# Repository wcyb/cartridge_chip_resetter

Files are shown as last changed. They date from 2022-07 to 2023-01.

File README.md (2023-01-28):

# Cartridge chip resetter

This repository contains electronic schematics and source code for resetters of chips placed on ink and toner cartridges. Resetters allow the same cartridge to be reused any number of times after it has been refilled with ink or toner respectively. This allows for maximum reduction in printing costs, as you only need to refill the cartridges and reset their chips when necessary, instead of buying a new cartridge every time.

Ready-made resetters of Chinese origin, for different cartridge models can be purchased on various sites, such as AliExpress or eBay. If you want to make such a resetter for your printer yourself, you can use this repository.

For more information on how the DRM protections used in printer cartridges work, and how to analyze them and create resetters yourself, see my research paper, available here: [research paper](https://czasopisma.uwm.edu.pl/index.php/ts/article/view/7634).

Currently, this repository contains documentation of resetters for printers and MFPs from two manufacturers - EPSON and RICOH.

These resetters should work with chips from cartridges used in the following printer/MFP models:

| EPSON | RICOH |
|---|---|
| B40W | SG 2100N |
| BX300F | SG 3100 SNw |
| BX310F | SG 3110DN |
| BX600FW | SG 3110DNw |
| BX610FW | SG 3110 SFNw  |
| D78 | SG 3120B SFNw |
| D92 | SG 7100DN |
| D120 | SP 100 |
| DX4000 | SP 100E |
| DX4050 | SP 100SU |
| DX4400 | SP 100SF |
| DX4450 | SP 112 |
| DX5000 | SP 112SU |
| DX5050 | SP 112SF |
| DX6000 | |
| DX6050 | |
| DX7000 | |
| DX7000F | |
| DX7400 | |
| DX7450 | |
| DX8400 | |
| DX8450 | |
| DX9000 | |
| DX9400 | |
| DX9400F | |
| DX9450 | |
| DX945 | |
| S20 | |
| S21 | |
| SX100 | |
| SX105 | |
| SX110 | |
| SX115 | |
| SX200 | |
| SX210 | |
| SX215 | |
| SX218 | |
| SX400 | |
| SX405 | |
| SX405WiFi | |
| SX410 | |
| SX415 | |
| SX510W | |
| SX515W | |
| SX600FW | |
| SX610FW | |

Cartridge models:

| EPSON | Compatible resetter | RICOH | Compatible resetter |
|---|---|---|---|
| T0711 | DX4050 | GC 41K  | SG2100N |
| T0712 | DX4050 | GC 41C  | SG2100N |
| T0713 | DX4050 | GC 41M  | SG2100N |
| T0714 | DX4050 | GC 41Y  | SG2100N |
| | | GC 41KL | SG2100N |
| | | GC 41CL | SG2100N |
| | | GC 41ML | SG2100N |
| | | GC 41YL | SG2100N |
| | | _IC 41_ | SG2100N |
| | | 407166  | SP112 |

This gives a total of 13 cartridge models and 1 waste ink container model, used in 60 different printer and MFP models.

A data map for the chip used in each cartridge model is also included in the folders for each of the resetters. It is not guaranteed to be completely compatible with chip data from printer models other than the one on which it was based. However, if there are any differences, they should be minor and not affect the functioning of the resetter.

I don't plan to create any more resetters as I don't own any other printer models. If someday I have a new printer, then maybe the documentation for another resetter will appear here.

### Non-commercial use only.

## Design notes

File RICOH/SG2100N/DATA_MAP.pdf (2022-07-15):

## Data map of RICOH AFICIO SG 2100N cartridge chip’s memory

| 0x00 | 0x01 | 0x02 | 0x03 | 0x04 | 0x05 | 0x06 | 0x07
0x00 | M¹ | CV² | B 3 | Region⁴ | T 5 | IC⁶ | 0x0 | 0xFF
0x08 | IIA⁷ | 0x0 | 0xFF | | | | ISR⁸ | 0xFF
0x10 | Cartridge serial number⁹
0x18 | 0xFF
0x20 | EDP code¹⁰
0x28 | PL¹¹ | 0x0
0x30 | 0xFF
0x38
0x40 | IED¹² | Ink amount | Printer work status (PWS)
0x48 | PWS | IIC¹³ | HRC¹⁴ | HCC¹⁵ | AIC¹⁶ | ISF¹⁷ | SF¹⁸ | 0xFF
0x50 | 0xFF | | | | | | CPC¹⁹
0x58 | BPC²⁰ | | EPC²¹ | | TPC²²
0x60 | Amount of ink used
0x68 | 0xFF
0x70 | Cartridge status
0x78 | Printer serial number

1 Model
2 Cartridge version
3 Brand
4 Region of destination of the cartridge (e.g. Europe) 5 Type
6 Ink color – 1:black, 2:cyan, 3:magenta, 4:yellow 7 The initial amount of ink in percent
8 The number of refills of the ink delivery system
9 Two digits are coded on each byte
10 One of the following: 405761, 405762, 405763, 405764, 405765, 405766, 405767, 405768 11 Percentage of ink left (100 means full, 255 means not initialized)
12 Ink expiration date
13 The amount of ink used during cartridge initialization
14 The number of print head refresh cycles
15 The number of print head cleaning cycles
16 The number of air intrusions into the ink delivery system 17 The number of fills of the ink delivery system
18 Status flag
19 The number of color pages printed
20 The number of black and white pages printed 21 The number of economy color pages printed 22 The number of total pages printed

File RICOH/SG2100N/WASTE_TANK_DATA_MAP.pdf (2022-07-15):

Data map of RICOH AFICIO SG 2100N waste tank chip’s memory

| 0x00 | 0x01 | 0x02 | 0x03 | 0x04 | 0x05 | 0x06 | 0x07
0x00 | M¹ | CV² | B 3 | CN⁴ | 0x0 | Amount of ink used (AIU)
0x08 | AIU | Serial number (SN)
0x10 | SN | TF⁵ | | TCF⁶ | 0x0
0x18 | Printer serial number
0x20 | 0x0
0x28 | TPC⁷
0x30 | 0x0 | WSF⁸ | 0x0
0x38 | CPC⁹
0x40
0x48 | 0x0
0x50
0x58 | Tank status | 0x0 | SF¹⁰ | WSF
0x60 | WSF | 0x0 | WSF | 0x0
0x68 | 0x0 | AIS¹¹ | CPC
0x70 | 0x0 | BPC¹² | Counter (C)
0x78 | C | 0x0
0x80 | AIS | 0x0 | ISF¹³
0x88 | 0x0
⁞ | ⁞
0xFF | 0x0

1 Model
2 Cartridge version
3 Brand
4 Control number
5 Threshold value indicating a full tank
6 Threshold value indicating a tank close to full 7 The number of total pages printed
8 Work status flag
9 The number of color pages printed
10 Status flag
11 The number of air intrusions into the ink delivery system 12 The number of black and white pages printed
13 The number of fills of the ink delivery system

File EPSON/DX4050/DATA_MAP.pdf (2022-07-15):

## Data map of Epson Stylus DX4050 cartridge chip’s memory

| 0x00 | 0x01 | 0x02 | 0x03 | 0x04 | 0x05 | 0x06 | 0x07
0x00 | Chip ID¹ | Ink dot counter | | | AU² | Static data
0x08 | Static data | | | 0xB2 | Ink color³ | | Static data
0x10 | „EPSON” string | | | | | Static data
0x18 | 0x00

1 0x3C – black, 0xFC – yellow, 0xBC – magenta, 0x7C – cyan
2 Amount of ink used (0x00 – full, 0xFF – empty)
3 0xC3,0x65 – black, 0x83,0x66 – yellow, 0x43,0x67 – magenta, 0x03,0x68 – cyan

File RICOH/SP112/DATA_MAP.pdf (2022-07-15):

Data map of RICOH SP112 cartridge chip’s memory

| 0x00 | 0x01 | 0x02 | 0x03 | 0x04 | 0x05 | 0x06 | 0x07
0x00 | M¹ | CV² | B 3 | Region⁴ | Cartridge type⁵ | | | 0x00
0x08 | IT⁶ | 0x00 | EDP code (407166)
0x10 | Cartridge serial number
0x18 | 0x00 | | | | Control number
0x20 | Printer serial number
0x28 | PT⁷ | OW⁸
0x00
0x30
0x00
0x38
0x40 | Number of pages printed | 0x00
0x48 | 0x00
0x50
0x58 | Control number | 0x00
0x60 | 0x00
0x68 | CC⁹ | 0x00
0x70 | Amount of toner used | 0x00 | WT¹⁰ | BF¹¹
0x78 | 0x00

1 Model
2 Cartridge version
3 Brand
4 Region of destination of the cartridge (e.g. Europe)
5 Cartridge type (0x01,0x01,0x03 – starter, 0x03,0x01,0x01 – standard) 6 The initial amount of toner in percent
7 The percentage of toner remaining
8 OPC drum wear
9 Number of cartridge cleaning cycles
10 The percentage filling level of the waste toner container 11 Bit field (cardridge status)

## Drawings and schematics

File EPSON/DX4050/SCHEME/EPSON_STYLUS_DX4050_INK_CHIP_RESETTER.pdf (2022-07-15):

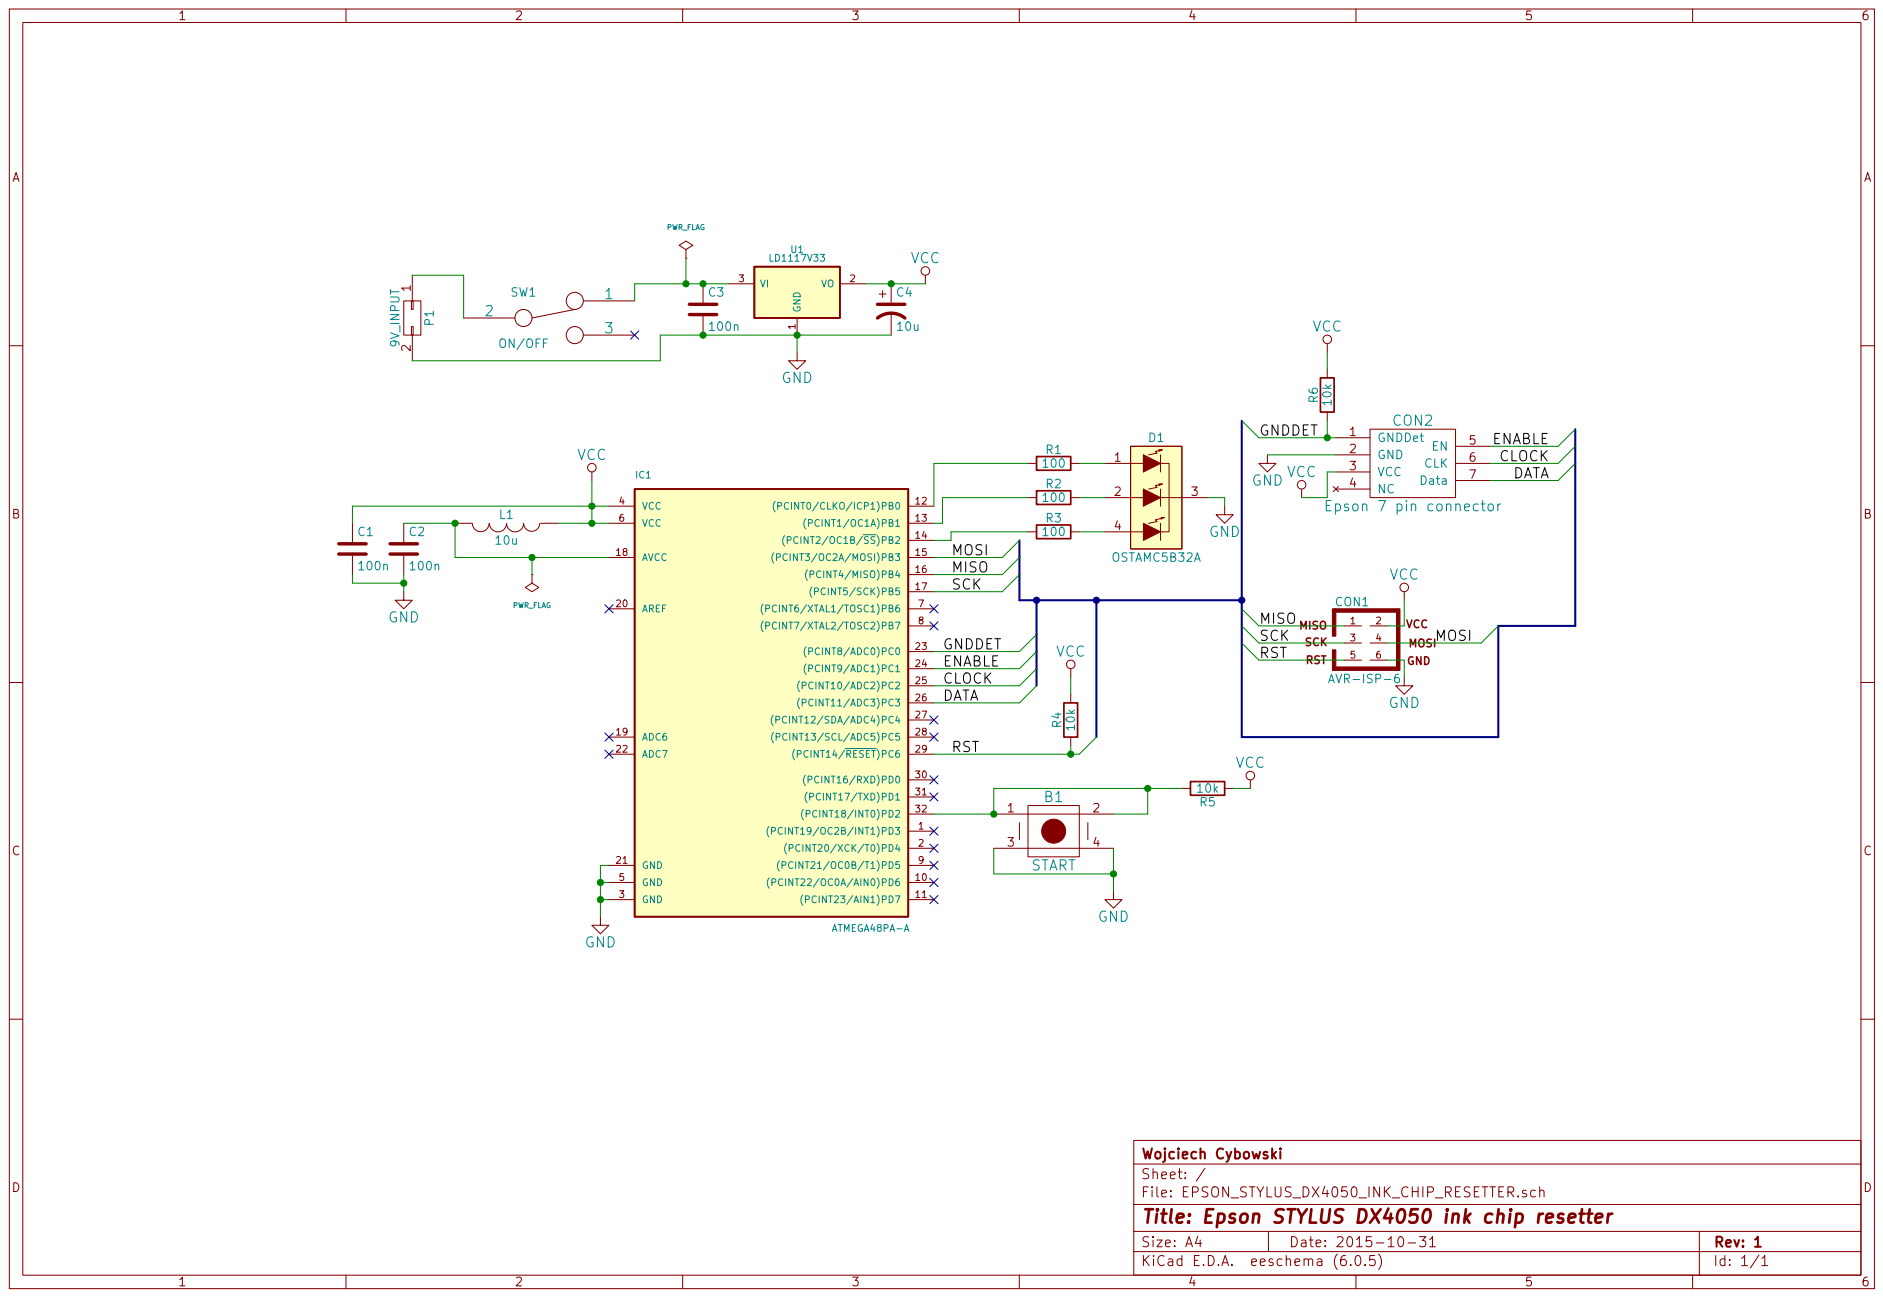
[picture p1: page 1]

File: EPSON_STYLUS_DX4050_INK_CHIP_RESETTER.sch Sheet: / Wojciech Cybowski

Id: 1/1 Title: Epson STYLUS DX4050 ink chip resetter

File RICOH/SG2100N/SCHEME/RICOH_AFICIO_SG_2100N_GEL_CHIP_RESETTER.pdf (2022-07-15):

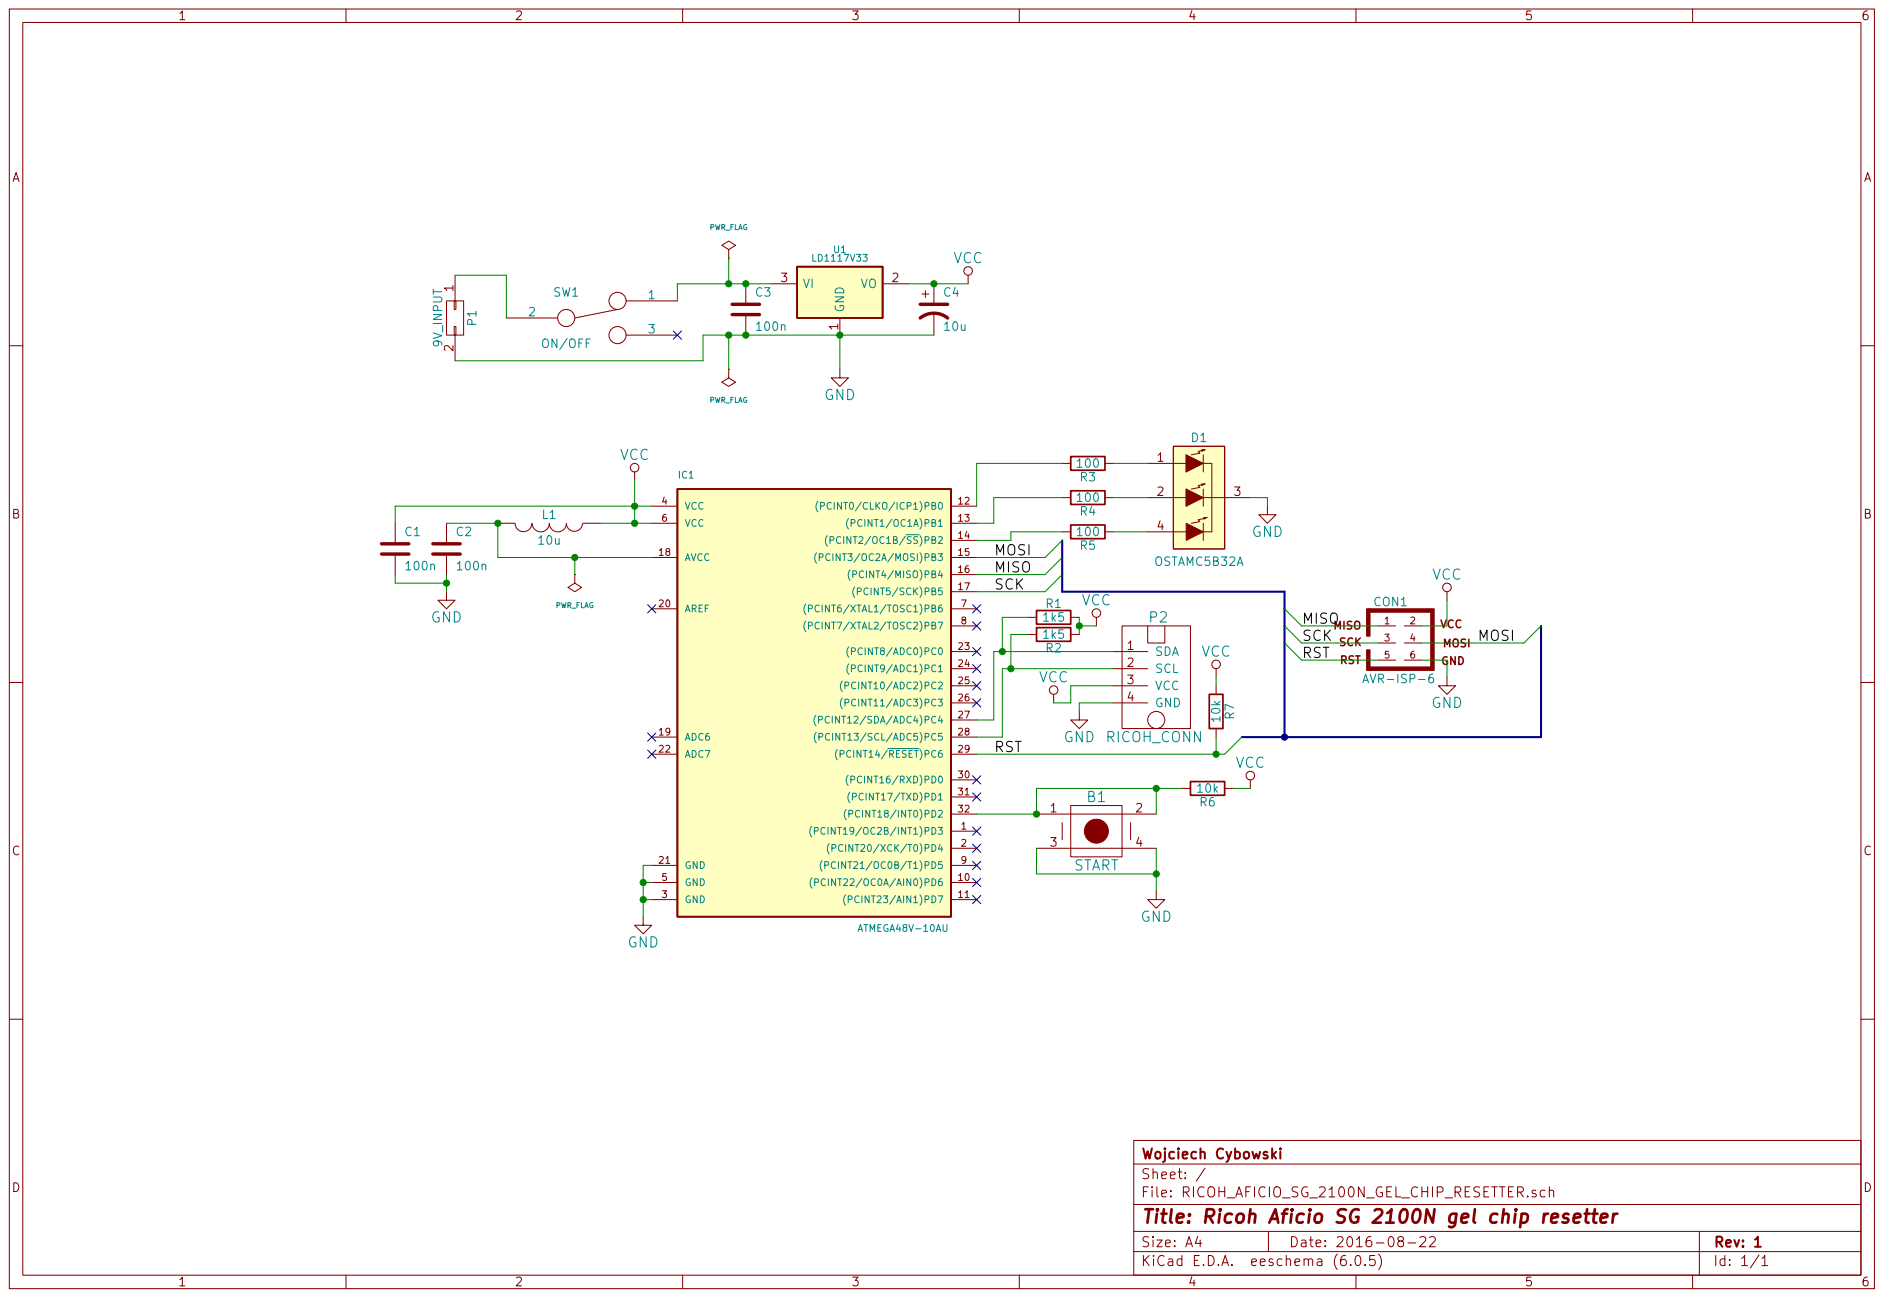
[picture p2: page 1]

File: RICOH_AFICIO_SG_2100N_GEL_CHIP_RESETTER.sch Sheet: / Wojciech Cybowski

Id: 1/1 Title: Ricoh Aficio SG 2100N gel chip resetter

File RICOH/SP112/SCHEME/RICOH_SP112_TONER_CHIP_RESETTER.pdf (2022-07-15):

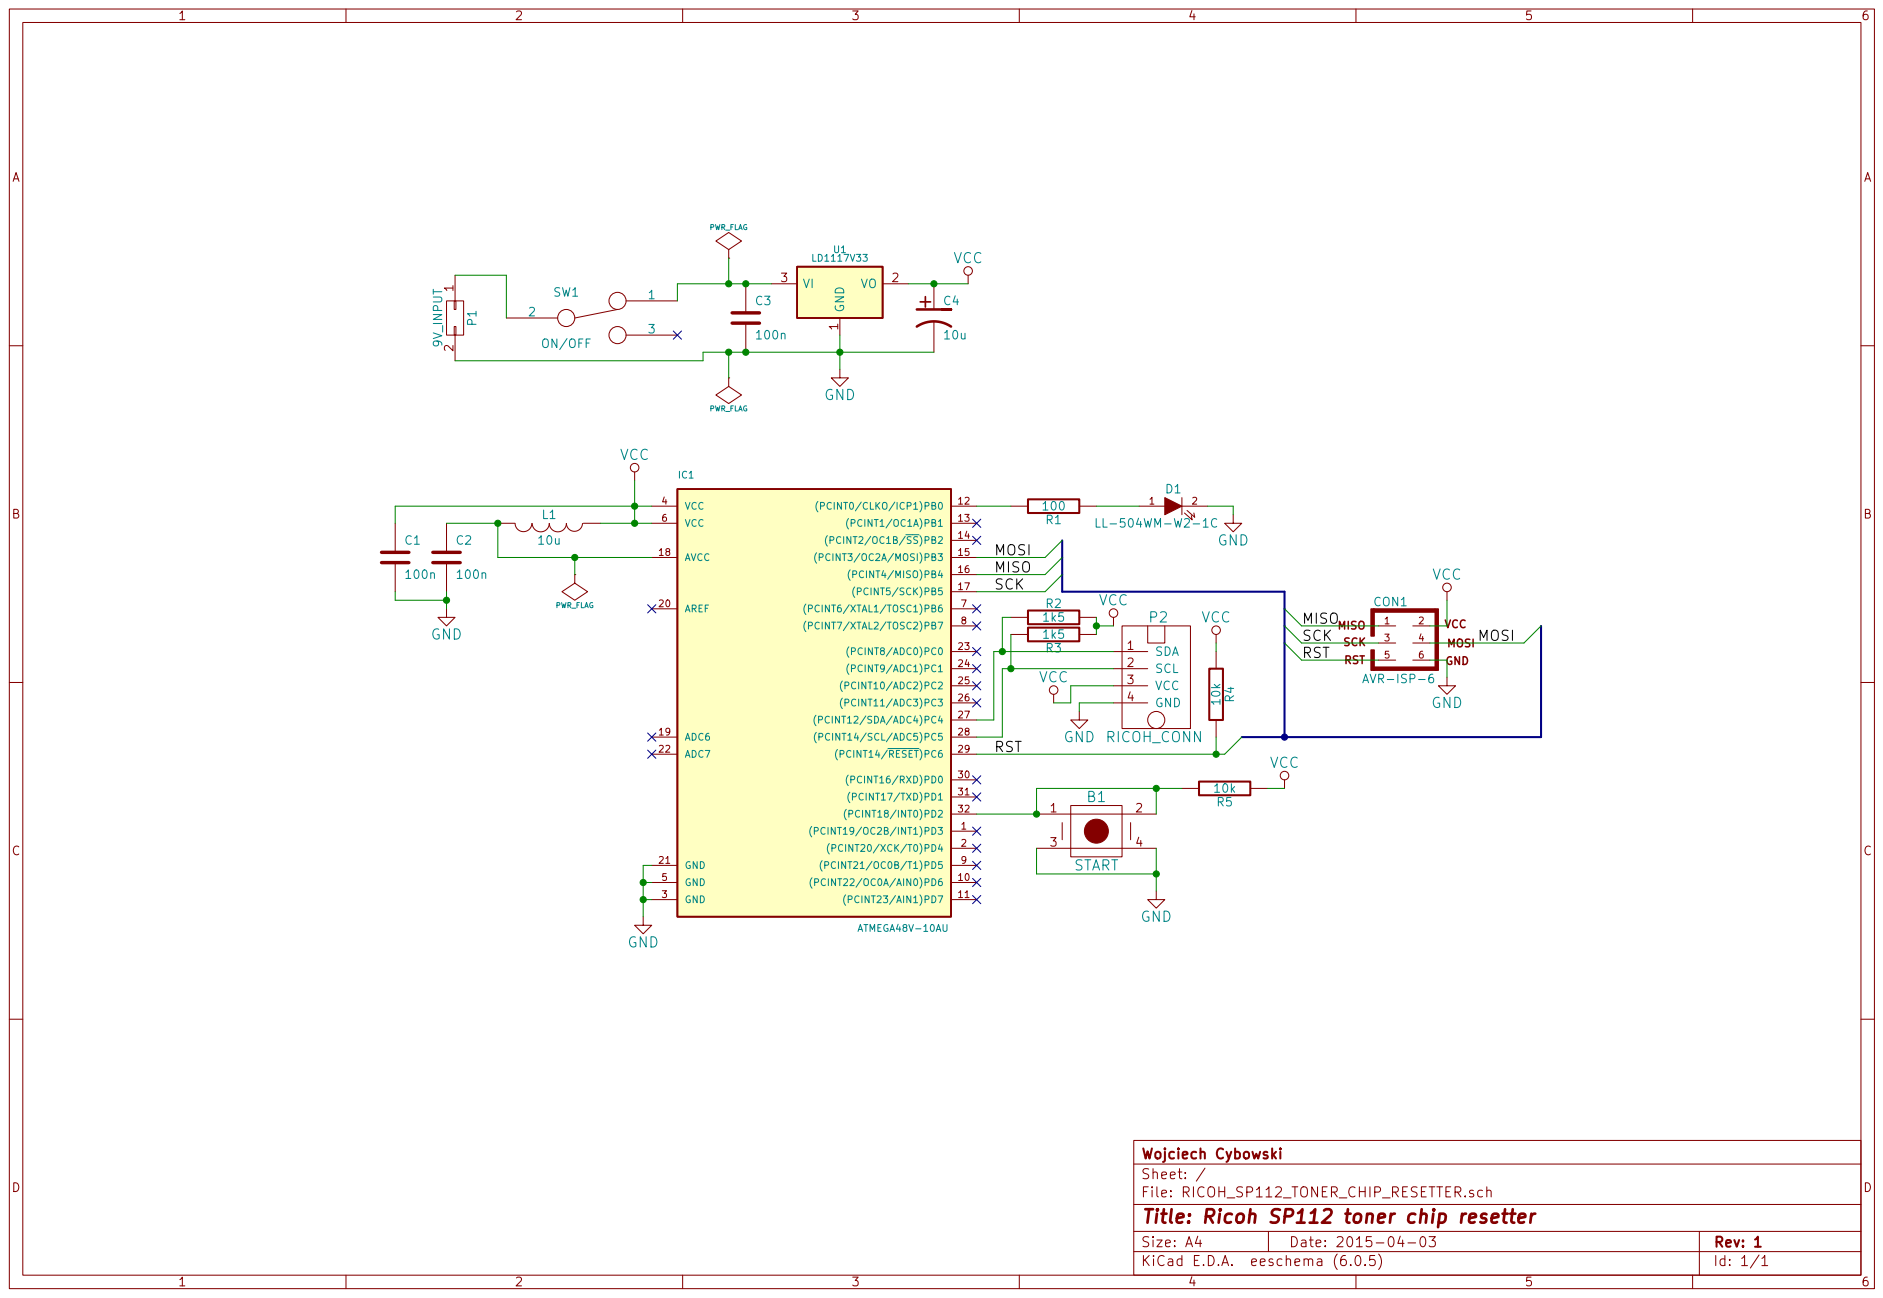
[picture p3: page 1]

File: RICOH_SP112_TONER_CHIP_RESETTER.sch Sheet: / Wojciech Cybowski

Id: 1/1 Title: Ricoh SP112 toner chip resetter

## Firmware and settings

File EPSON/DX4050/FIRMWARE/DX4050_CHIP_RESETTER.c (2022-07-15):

/*
* DX4050_CHIP_RESETTER.c
*
* Created: 01-11-2015 04:42:36
* Author: Wojciech Cybowski
* https://github.com/wcyb/cartridge_chip_resetter
*
*/

#define F_CPU 8000000UL //8MHz

#include <avr/io.h>
#include <avr/interrupt.h>
#include <stdbool.h>
#include <util/delay.h>
#include <avr/sfr_defs.h>

#define blackChipReadAddr 0x27 //4 bit ID, 4 bit "NACK"
#define magentaChipReadAddr 0xA7
#define yellowChipReadAddr 0xE7
#define cyanChipReadAddr 0x67

#define blackChipWriteAddr 0x3F //4 bit ID, 4 bit "NACK"
#define magentaChipWriteAddr 0xBF
#define yellowChipWriteAddr 0xFF
#define cyanChipWriteAddr 0x7F

#define dataWriteSize 4
#define dataReadSize 32
#define startEndSize 10
//----------------------
#define redLed 4
#define greenLed 1
#define blueLed 2
#define yellowLed 5
#define whiteLed 7
#define offLed 0
//----------------------
#define delay100khz 0x0A
#define delay40khz 0x19
#define delay10khz 0x64
//----------------------
#define chipPrt PORTC
#define gndDet PINC0
#define en PINC1
#define clk PINC2
#define data PINC3
//----------------------
const uint8_t startData[] = {6, 0, 17, 96, 1, 6, 0, 17, 96, 0}; //header packet
const uint8_t endData[] = {6, 0, 1, 96, 1, 6, 0, 17, 96, 0}; //trailer packet
//4 bit adresses of black, magenta, yellow, cyan chips and 4 bit "ACK", then first byte values for each color, second byte value and 3 byte trailer
const uint8_t dataToCheck[] = {44, 172, 236, 108, 195, 67, 131, 3, 101, 103, 102, 104, 12, 98, 39};
volatile bool startResetting = false; //if true then user pressed the button
volatile uint8_t cartridgeChipData[dataReadSize] = {0};
volatile uint8_t resetChipData[dataWriteSize] = {0}; //this array will hold information for writing to the connected chip
//----------------------
uint8_t findConnectedChip(void); //0 - nothing connected, 1 - black, 2 - magenta, 3 - yellow, 4 - cyan
uint8_t readDataFromChip(uint8_t); //argument value 1-4 depends on found chip, returns 1 if the read data is wrong, 0 if all is ok
uint8_t resetInkCounter(uint8_t); //argument value 1-4 depends on found chip, returns 1 if resetting was not ok, 0 if all is ok
void sendData(const uint8_t[], uint8_t); //sends array of data, args are array and array size
void clearArray(volatile uint8_t[], uint8_t); //clears given array, arguments are array and array size
void blinkLed(uint8_t, uint8_t); //arguments are blink type and error mode, 0 - error(error mode can be set from 1 to 3), 1 - black resetted, 2 - magenta, 3 - yellow, 4 - cyan
void pulseAndSetEn(void); //pulses and leaves the EN pin in high state

int main(void)
{
    DDRB = 0x7; //pins 1, 2, 3 are outputs, the rest are inputs
    DDRC = 0xE; //pins 2, 3, 4 are outputs
    DDRD = 0x0; //set input type for the button, the rest of pins are also inputs
    PORTB = 0xF8;
    PORTC = 0x30;
    PORTD = 0xFB;
    //----------------------------------------------
    EICRA |= (1 << ISC01); //INT0 on falling edge
    EIMSK |= (1 << INT0); //enable INT0
    //----------------------------------------------
    chipPrt &= ~(1 << en); //set defaults
    chipPrt &= ~(1 << clk);
    chipPrt &= ~(1 << data);
    //----------------------------------------------
    sei(); //enable interrupts

    while (1)
    {
        if (startResetting == true)
        {
            EIMSK &= ~(1 << INT0); //disable INT0 for the time of resetting
            sendData(startData, startEndSize);
            uint8_t foundChip = findConnectedChip();
            if (foundChip == 0) //if nothing was found
            {
                blinkLed(0, 1); //indicate that chip was not found
            }
            else //if some chip was found
            {
                uint8_t readingResult = readDataFromChip(foundChip);
                if (readingResult == 1)
                {
                    blinkLed(0, 2); //indicate that wrong data was read
                }
                else
                {
                    uint8_t resetResult = resetInkCounter(foundChip);
                    if (resetResult == 1)
                    {
                        blinkLed(0, 3);
                    }
                    else
                    {
                        blinkLed(foundChip, 0); //if reset was ok then indicate it
                    }
                }
            }
            sendData(endData, startEndSize);
            clearArray(cartridgeChipData, dataReadSize);
            clearArray(resetChipData, dataWriteSize);
            EIMSK |= (1 << INT0); //enable INT0 again
            EIFR |= (1 << INTF0); //clear INT0 flag, this will eliminate additional reading after release of button
            startResetting = false; //end resetting
        }
    }
}

uint8_t findConnectedChip(void) //0 - nothing connected, 1 - black, 2 - magenta, 3 - yellow, 4 - cyan
{
    uint8_t chipAddresses[] = {blackChipReadAddr, magentaChipReadAddr, yellowChipReadAddr, cyanChipReadAddr};
    uint8_t actualAddress = 0;
    uint8_t chipResponse = 0;

    if (bit_is_set(PINC, gndDet))
    {
        return 0; //if gndDetect is high then chip is not connected
    } //else go on

    for (uint8_t addrNum = 0; addrNum < 4; addrNum++)
    {
        actualAddress = chipAddresses[addrNum]; //first select one of the addresses
        pulseAndSetEn(); //indicate that next transmission will occur
        for (uint8_t i = 128; i > 8; i /= 2) //MSB first, send only first nibble of the address
        {
            chipPrt &= ~(1 << clk); //send first part of the address
            if (actualAddress & i) //if on actualAddress bit position i is 1 then change the data line state
            {
                chipPrt |= (1 << data);
            }
            else
            {
                chipPrt &= ~(1 << data);
            }
            _delay_us(delay40khz); //after setting a state on the data pin, wait a while to let output value latch into chip input
            chipPrt |= (1 << clk);
            _delay_us(delay100khz); //on state should be shorter than off state
        }
        chipPrt &= ~(1 << clk);
        chipPrt &= ~(1 << data); //now read the response from the chip
        DDRC = 0x6; //set the data line as input for now
        for (uint8_t bitNum = 8; bitNum > 0; bitNum /= 2)
        {
            chipPrt &= ~(1 << clk);
            _delay_us(delay40khz);
            chipPrt |= (1 << clk);
            if (bit_is_set(PINC, data))
            {
                chipResponse |= bitNum; //set 1 on given bit
            }
            _delay_us(delay100khz);
        }
        chipPrt &= ~(1 << clk);
        DDRC = 0xE; //set the data line as output
        chipPrt &= ~(1 << data);
        if (chipResponse == 0x0C) //chip is found, this part should always be 0x0C "ACK"
        {
            chipPrt &= ~(1 << clk);
            chipPrt &= ~(1 << data);
            chipPrt &= ~(1 << en);
            DDRC = 0xE; //set the data line as output
            return addrNum + 1; //the data line will stay in input mode in case a cartridge chip was found
        }
        chipPrt &= ~(1 << en);
        chipResponse = 0; //in case that a chip with given address was not found, reset response
    }
    return 0; //if chip was not found then return 0
}

uint8_t readDataFromChip(uint8_t inkColor) //argument value 1-4 depends on found chip, returns 1 if the read data is wrong, 0 if all is ok
{
    uint8_t chipAddresses[] = {blackChipReadAddr, magentaChipReadAddr, yellowChipReadAddr, cyanChipReadAddr};
    uint8_t actualAddress = 0;
    uint8_t temp = 0;

    DDRC = 0xE; //set the data line as output
    pulseAndSetEn();
    actualAddress = chipAddresses[inkColor - 1];
    for (uint8_t i = 128; i > 8; i /= 2) //MSB first, now we know the address so we will start a transmission to this address
    {
        chipPrt &= ~(1 << clk);
        if (actualAddress & i) //if on actualAddress bit position i is 1 then change the data line state
        {
            chipPrt |= (1 << data);
        }
        else
        {
            chipPrt &= ~(1 << data);
        }
        _delay_us(delay40khz);
        chipPrt |= (1 << clk);
        _delay_us(delay100khz);
    }
    chipPrt &= ~(1 << clk);
    chipPrt &= ~(1 << data); //after transmitting the address of found chip we can read response
    DDRC = 0x6; //set the data line as input for now

    cartridgeChipData[0] = actualAddress & 0xF0; //keep the chip ID and prepare for "ACK" or "NACK"
    actualAddress = cartridgeChipData[0];
    for (uint8_t bitNum = 8; bitNum > 0; bitNum /= 2) //read the second nibble of the first byte
    {
        chipPrt &= ~(1 << clk);
        _delay_us(delay40khz);
        chipPrt |= (1 << clk);
        if (bit_is_set(PINC, data))
        {
            actualAddress |= bitNum; //set 1 on given bit
        }
        _delay_us(delay100khz);
    }
    chipPrt &= ~(1 << clk);
    cartridgeChipData[0] = actualAddress; //now we have the first byte

    for (uint8_t i = 1; i < dataReadSize; i++)
    {
        for (uint8_t bitNum = 128; bitNum > 0; bitNum /= 2)
        {
            chipPrt &= ~(1 << clk);
            _delay_us(delay40khz);
            chipPrt |= (1 << clk);
            if (bit_is_set(PINC, data))
            {
                temp |= bitNum; //set 1 on given bit
            }
            _delay_us(delay100khz);
        }
        chipPrt &= ~(1 << clk);
        cartridgeChipData[i] = temp;
        temp = 0;
    }
    chipPrt &= ~(1 << en);
    DDRC = 0xE; //set the data line as output
    chipPrt &= ~(1 << data);
    //now we can check the received data
    if (cartridgeChipData[0] != dataToCheck[inkColor - 1]) //check if the connected chip send "ACK"
    {
        return 1;
    }
    if (cartridgeChipData[12] != dataToCheck[3 + inkColor] || cartridgeChipData[13] != dataToCheck[7 + inkColor]) //check if the chip ID corresponds to the ink color
    {
        return 1;
    }
    for (uint8_t i = 14; i > 11; i--) //check the last 3 trail bytes
    {
        if (cartridgeChipData[9 + i] != dataToCheck[i])
        {
            return 1;
        }
    }
    return 0; //if everything is ok
}

uint8_t resetInkCounter(uint8_t inkColor) //argument value 1-4 depends on found chip, returns 1 if resetting was not ok, 0 if all is ok
{
    uint8_t chipAddresses[] = {blackChipWriteAddr, magentaChipWriteAddr, yellowChipWriteAddr, cyanChipWriteAddr};
    uint8_t temp = 0;

    for (uint8_t i = 0; i < dataWriteSize; i++) //first copy data that we will need
    {
        resetChipData[i] = cartridgeChipData[i + 1]; //copy data after the first byte(read address), because we use a different address when writing data
    }
    resetChipData[3] = 0; //reset ink usage

    DDRC = 0xE; //set the data line as output
    pulseAndSetEn();
    temp = chipAddresses[inkColor - 1];
    for (uint8_t i = 128; i > 0; i /= 2) //MSB first
    {
        chipPrt &= ~(1 << clk);
        if (temp & i) //if on actualAddress bit position i is 1 then change the data line state
        {
            chipPrt |= (1 << data);
        }
        else
        {
            chipPrt &= ~(1 << data);
        }
        _delay_us(delay10khz);
        chipPrt |= (1 << clk);
        _delay_us(delay100khz);
    }
    chipPrt &= ~(1 << clk);
    chipPrt &= ~(1 << data);
    temp = 0;
    for (uint8_t pos = 0; pos < dataWriteSize; pos++) //start writing of zeroed ink usage count
    {
        temp = resetChipData[pos];
        for (uint8_t i = 128; i > 0; i /= 2) //MSB first
        {
            chipPrt &= ~(1 << clk);
            if (temp & i) //if on actualAddress bit position i is 1 then change the data line state
            {
                chipPrt |= (1 << data);
            }
            else
            {
                chipPrt &= ~(1 << data);
            }
            _delay_us(delay10khz);
            chipPrt |= (1 << clk);
            _delay_us(delay100khz);
        }
        _delay_ms(6); //wait for writing of the sent byte
        chipPrt &= ~(1 << clk);
        chipPrt &= ~(1 << data); //change the state of the data line in case the last bit was 1
    }
    chipPrt &= ~(1 << en);
    //now check if writing was successful
    clearArray(cartridgeChipData, dataReadSize);
    uint8_t readResult = readDataFromChip(inkColor);
    if (readResult == 1)
    {
        return 1;
    }
    for (uint8_t i = 0; i < dataWriteSize; i++) //if chip was read ok then check if was resetted correctly
    {
        if (resetChipData[i] != cartridgeChipData[i + 1])
        {
            return 1;
        }
    }
    return 0;
}

void sendData(const uint8_t dataToSend[], uint8_t sizeOfData)
{
    uint8_t temp = 0;
    DDRC = 0xE; //set the data line as output
    pulseAndSetEn();
    for (uint8_t pos = 0; pos < sizeOfData; pos++)
    {
        temp = dataToSend[pos];
        for (uint8_t i = 128; i > 0; i /= 2) //MSB first
        {
            chipPrt &= ~(1 << clk);
            if (temp & i) //if on actualAddress bit position i is 1 then change the data line state
            {
                chipPrt |= (1 << data);
            }
            else
            {
                chipPrt &= ~(1 << data);
            }
            _delay_us(delay40khz);
            chipPrt |= (1 << clk);
            _delay_us(delay100khz);
        }
        chipPrt &= ~(1 << clk);
        chipPrt &= ~(1 << data);
    }
    chipPrt &= ~(1 << en);
}

void clearArray(volatile uint8_t arrayToClear[], uint8_t sizeOfArray) //clears given array, arguments are array and array size
{
    for (uint8_t i = 0; i < sizeOfArray; i++)
    {
        arrayToClear[i] = 0;
    }
}

void blinkLed(uint8_t mode, uint8_t errorMode)
{
    //0 - error, 1 - black, 2 - magenta, 3 - yellow, 4 - cyan
    switch (mode)
    {
        case 0: //error, 1 white blink - chip not found, 2 white blinks - wrong data read, 3 white blinks - ink counter not resetted
            for (uint8_t i = 0; i < errorMode; i++)
            {
                PORTB = whiteLed;
                _delay_ms(250);
                PORTB = offLed;
                _delay_ms(250);
            }
            break;

        case 1: //black resetted
            PORTB = whiteLed;
            _delay_ms(3000);
            PORTB = offLed;
            break;

        case 2: //magenta resetted
            PORTB = redLed;
            _delay_ms(3000);
            PORTB = offLed;
            break;

        case 3: //yellow resetted
            PORTB = yellowLed;
            _delay_ms(3000);
            PORTB = offLed;
            break;

        case 4: //cyan resetted
            PORTB = blueLed;
            _delay_ms(3000);
            PORTB = offLed;
            break;
    }
}

void pulseAndSetEn(void)
{
    chipPrt |= (1 << en);
    _delay_us(60);
    chipPrt &= ~(1 << en);
    _delay_us(5);
    chipPrt |= (1 << en);
}

ISR(INT0_vect)
{
    startResetting = true;
}

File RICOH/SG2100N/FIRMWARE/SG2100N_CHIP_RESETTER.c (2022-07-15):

/*
* SG2100N_CHIP_RESETTER.c
*
* Created: 28-08-2017 03:25:14
* Author: Wojciech Cybowski
* https://github.com/wcyb/cartridge_chip_resetter
*
*/

#define F_CPU 8000000UL //8MHz

#include <avr/io.h>
#include <avr/interrupt.h>
#include <stdbool.h>
#include <util/delay.h>
#include "i2cmaster.h"

#define chipAddrC 0xA2 //address of the cyan gel chip
#define chipAddrM 0xA4 //address of the magenta gel chip
#define chipAddrY 0xA6 //address of the yellow gel chip
#define chipAddrB 0xA0 //address of the black gel chip
#define chipAddrW 0xA8 //address of the waste tank chip

#define chipDataSize 1
#define chipTypeSize 2

#define redLed 4
#define greenLed 1
#define blueLed 2
#define yellowLed 5
#define whiteLed 7
#define offLed 0

volatile bool startResetting = false; //if true then user pressed the button
bool chipTypeOk = false; //if true then we can start resetting
bool resettedOk = false; //if true then chip was resetted successfully
const uint8_t chipsAddr[] = {chipAddrC, chipAddrM, chipAddrY, chipAddrB, chipAddrW};
const uint8_t gelType[chipTypeSize] = {227, 18};
const uint8_t wasteType[chipTypeSize] = {227, 1};
const uint8_t dataToCheck[chipDataSize] = {100};
volatile uint8_t readData[chipDataSize] = {0};
volatile uint8_t readChipType[chipTypeSize] = {0};

uint8_t findChip(void); //searches for a gel or waste tank chip, returns a number from 1 to 5 in order C M Y B W, or 0 if a chip was not found
void writeZeros(uint8_t, uint8_t, uint8_t); //writes given number of zeros starting from given address
uint8_t checkZeros(uint8_t, uint8_t, uint8_t); //reads data and checks if all read bytes are 0
void writeOnes(uint8_t, uint8_t, uint8_t); //writes given number of ones starting from given address
uint8_t checkOnes(uint8_t, uint8_t, uint8_t); //reads data and checks if all read bytes are 1
void blinkLed(uint8_t, uint8_t); //arguments are blink type and error mode, 0 - error(error mode can be set from 1 to 3), 1 - cyan resetted, 2 - magenta, 3 - yellow, 4 - black, 5 - waste tank

int main(void)
{
    DDRB = 0x07; //set output for LED
    DDRD &= ~(1 << PIND2); //set input for the button
	PORTB = 0xF8; //pull-up unused pins to vcc
	PORTC = 0x3F; //pull-up
	PORTD = 0xFB; //pull-up
    //----------------------------------------------
    EICRA |= (1 << ISC01); //INT0 on falling edge
    EIMSK |= (1 << INT0); //enable INT0
    //----------------------------------------------
    i2c_init(); //initialize I2C library
    sei(); //enable interrupts

    while (1)
    {
        if (startResetting == true)
        {
            EIMSK &= ~(1 << INT0); //disable INT0 for the time of resetting
            uint8_t foundChip = findChip(); //search for the connected chip
            if (foundChip != 0) //chip was found
            {
                foundChip--; //subtract 1 because the function returns 0 when chip is not found, so all numbers are +1
                i2c_write(0x0);
                i2c_rep_start(chipsAddr[foundChip] + I2C_READ);
                readChipType[0] = i2c_readAck();
                readChipType[1] = i2c_readNak();
                i2c_stop();

                for (uint8_t i = 0; i < chipTypeSize; i++) //check if chip type matches
                {
                    if (readChipType[i] != gelType[i] && readChipType[i] != wasteType[i]) //check if read type don't matches any known value
                    {
                        chipTypeOk = false;
                        break;
                    }
                    chipTypeOk = true;
                }

                if (chipTypeOk == false)
                {
                    blinkLed(0, 2); //show that the chip type is wrong, stop resetting
                }
                else
                {
                    uint8_t zerosCheck = 0; //this var will indicate if needed data is 0's
                    uint8_t onesCheck = 0xFF; //this var will indicate if needed data is 1's
                    if (foundChip < 4) //if we reset a gel chip
                    {
                        writeZeros(chipsAddr[foundChip], 1, 0x06);
                        writeOnes(chipsAddr[foundChip], 1, 0x07);

                        i2c_start_wait(chipsAddr[foundChip] + I2C_WRITE); //set device address and write mode, repeated start
                        i2c_write(0x08); //initial ink level
                        i2c_write(100); //reset to full
                        i2c_stop();

                        writeZeros(chipsAddr[foundChip], 1, 0x09);
                        writeOnes(chipsAddr[foundChip], 6, 0x10);
                        writeOnes(chipsAddr[foundChip], 8, 0x18);
                        writeOnes(chipsAddr[foundChip], 1, 0x28);
                        writeZeros(chipsAddr[foundChip], 1, 0x29);
                        writeOnes(chipsAddr[foundChip], 22, 0x2A);
                        writeOnes(chipsAddr[foundChip], 11, 0x43);
                        writeOnes(chipsAddr[foundChip], 49, 0x4F);

                        //now check if data was written successfully
                        //read previously written values back from EEPROM
                        i2c_start_wait(chipsAddr[foundChip] + I2C_WRITE); //set device address and write mode
                        i2c_write(0x08); //initial ink level
                        i2c_rep_start(chipsAddr[foundChip] + I2C_READ); //set device address and read mode
                        readData[0] = i2c_readNak(); //read one byte from EEPROM
                        i2c_stop();

                        zerosCheck |= checkZeros(chipsAddr[foundChip], 1, 0x06);
                        zerosCheck |= checkZeros(chipsAddr[foundChip], 1, 0x09);
                        zerosCheck |= checkZeros(chipsAddr[foundChip], 1, 0x29);

                        onesCheck &= checkOnes(chipsAddr[foundChip], 1, 0x07);
                        onesCheck &= checkOnes(chipsAddr[foundChip], 6, 0x10);
                        onesCheck &= checkOnes(chipsAddr[foundChip], 8, 0x18);
                        onesCheck &= checkOnes(chipsAddr[foundChip], 1, 0x28);
                        onesCheck &= checkOnes(chipsAddr[foundChip], 22, 0x2A);
                        onesCheck &= checkOnes(chipsAddr[foundChip], 11, 0x43);
                        onesCheck &= checkOnes(chipsAddr[foundChip], 49, 0x4F);

                        for (uint8_t i = 0; i < chipDataSize; i++) //check if chip was resetted successfully
                        {
                            if (readData[i] != dataToCheck[i])
                            {
                                resettedOk = false;
                                break;
                            }
                            resettedOk = true;
                        }
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
